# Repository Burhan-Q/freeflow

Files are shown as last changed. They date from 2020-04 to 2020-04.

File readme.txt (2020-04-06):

This project contains hardware design (schematics & layout) and firmware design for a
small PCB used to sense air flow and air pressure.  The intent is to use a 3D printed 
Venturi tube with this board to help with the current Covid-19 medical emergency.
The project has two potential uses:

- Part of a larger ventilator project.  The airflow sensor is a key component of a ventilator
  design.

- Stand alone use for sharing a commercial ventilator among multiple patients.
  One problem with sharing a ventilator between patients is equalizing the flow.
  This sensor can be used inline at each patient to allow the emergency workers 
  to regulate flow using flow valves.

Note that I locally maintain my projects using Mercurial (hg) and am pushing to github
using the hg-git plugin.  There may be some odd files in the repo (like .hgignore) due
to that.  These can be ignored.

The schematics and layout files here were made using the open source gEDA tools; gschem
for schematic capture and pcb for layout.  These tools can be downloaded here:
   http://www.geda-project.org/

As of 4/6/20 this project is in the early stages.  There have been two revisions of the PCB
(check the git history to see earlier versions).  The main difference is the type of sensors
used to measure the pressure drop across the venturi tube.

Firmware is working but very preliminary.  Things like calibration values are hard coded at
the moment.  It's under active development and changing rapidly.

I'll try to keep this file updated as things progress.

- Steve Glow

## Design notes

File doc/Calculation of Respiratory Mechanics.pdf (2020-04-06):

## Calculation of Respiratory Mechanics

# Introduction:

Respiratory mechanics refers to the expression of lung function through measures of pressure and flow. They are very useful to know the status of the lungs of ventilated patients. Below is the screen shot of Hamilton Medical ventilator monitoring menu. This document will try to calculate as much as possible parameters from this menu, using data input from our flow meter and pressure sensor. This should be noted that this is a developing document and will be updated periodically

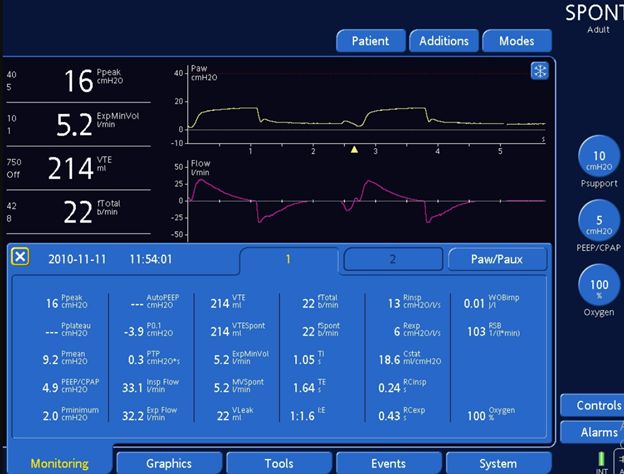
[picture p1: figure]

# 1) Alveolar Pressure:

For volume control setup like ours it’s calculated by

Palv = VT/CRS + PEEP.

VT <= set by us

PEEP<=set by us

CRS= calculated by Equation 6

# 2) Plateau Pressure

There are two methods to calculated it,

1) one is by holding the breath after inspiration for 0.5-1 second and measuring the pressure at inspiratory limb. This will be difficult in our setup of multiple patient.
2) The second method is using below equation and no hold breath maneuver is needed.

VT=tidal volume, set by us

PIP=peak inspiratory pressure , given by our pressure senor

PEEP=set by us

Time constant TE

is calculated by slope of expiratory flow curve between 0.1-0.5 seconds as shown below

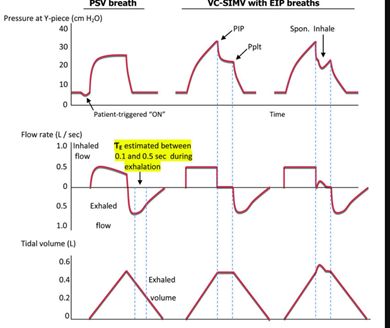
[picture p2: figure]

# 3) Auto-PEEP or iPEEP

Once again it can be calculated by two methods

a) Holding a breath after expiration and waiting for 0.5-1 second and measure pressing at proximal airway is Auto-PEEP, probably not applied in our case
b) It can also be calculated by mathematical equation

VT=tidal volume

CRS as calculated by equation-6

Kx=1/TE, and for TE see equation 2

# 4) Mean Airway Pressure

Calculated using following equation

PIP is peak inspiratory pressure

PEEP is known

TI

is time taken by respiration (SET BY US)

Ttot

total breathing cycle time

# 5) Respiratory System Compliance:

Defined in change in volume of respiratory system per unit of pressure

VT

=tidal volume

Pplat = See equation 2

PEEP=set by us

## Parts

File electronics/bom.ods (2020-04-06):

Item | Qty/board | Manufacturer | Part Number | Description | Value | Reference | Cost
1 | 1 | ST | STM32L412KBT6 | Processor |  | U1 | 2.46
2 | 1 | TI | TPS7B6933QDCYRQ1 | Linear regulator |  | U2 | 0.95
3 | 1 | JAE | DX4R005JJ2R1800 | Connector |  | J2 | 0.62
4 | 1 | Wurth | 150060VS75000 | LED | green | D3 | 0.11
5 | 1 | Wurth | 150060RS75000 | LED | red | D4 | 0.11
6 | 1 | CUI | CMT-0525-75-SMT-TR | Buzzer |  | U3 | 1.47
7 | 1 | Yageo | CC0603KRX7R9BB102 | Capacitor | 1nF | C3 | 0.01
8 | 1 | NXP | MP3V5004DP | Pressure sensor |  | U4
9 | 1 | NKK | A11JP | Switch |  | S2
10 | 2 | Yageo | RC0603FR-07150RL | Resistor | 150 | R1,R4 | 0.01
11 | 1 | Honeywell | MPRLS0001PG0000SA | Pressure sensor |  | U5 | 5.45
12 | 1 | E-switch | 800AWSP9M2QE | Push button |  | S3 | 2.41
13 | 4 | Toshiba | CUS10S30,H3F | Diode |  | D1,D5,D6,D7 | 0.1
14 | 1 | Nexperia | 74HC2G14GV,125 | Inverter |  | U7 | 0.21
15 | 1 | Yageo | CC0603KPX7R9BB103 | Capacitor | 0.01uF | C11 | 0.01
16 | 7 | Yageo | CC0603KRX7R8BB104 | Capacitor | 0.1uF | C12,C4,C5,C6,C7,C8,C9 | 0.01
17 | 1 | Samsung | CL10A105KP8NNNC | Capacitor | 1uF | C13 | 0.01
18 | 1 | Bourns | PEC12R-4222F-S0024 | Encoder |  | U8 | 0.8
19 | 1 | Hirose | DF13-2P-1.25DS(50) | Connector |  | J1 | 0.3
20 | 1 | Diodes Inc | DMN63D8LDW-7 | FET |  | Q1 | 0.1
21 | 1 | Hirose | DF13-4P-1.25DSA | Connector |  | J3 | 0.4
22 | 1 | Sullins | PPTC041LFBN-RC | Connector |  | J4 | 0.32
23 | 1 | Honeywell | HIH8120-021-001 | Humidity sensor |  | U6
24 | 1 | Molex | 705530003 | Connector |  | J5 | 0.8
25 | 8 | Yageo | RC0603FR-0710KL | Resistor | 10k | R10,R2,R3,R5,R6,R7,R8,R9 | 0.01
26 | 2 | Samsung | CL21A106KOQNNNG | Capacitor | 10uF | C1,C2 | 0.03

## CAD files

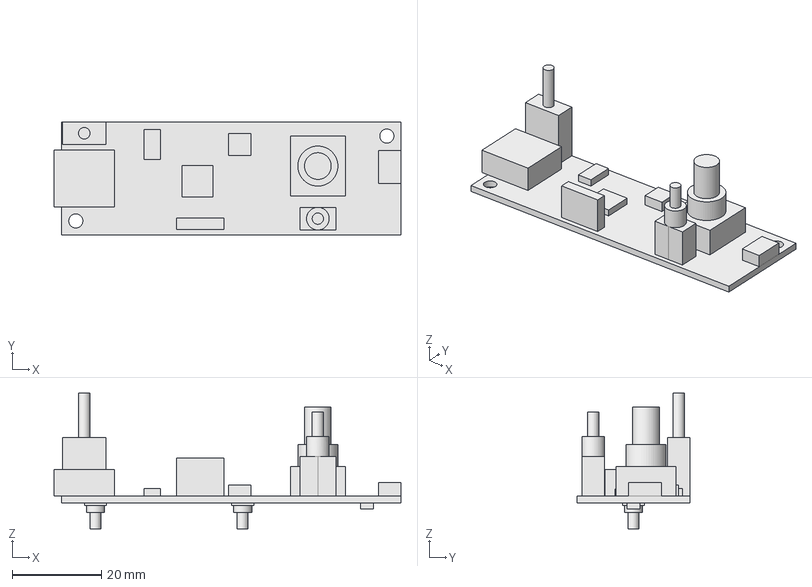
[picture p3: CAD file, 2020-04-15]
CAD/FreeFlow_board/freeflow2_ver2.step
77.9 x 25.4 x 30.5 mm

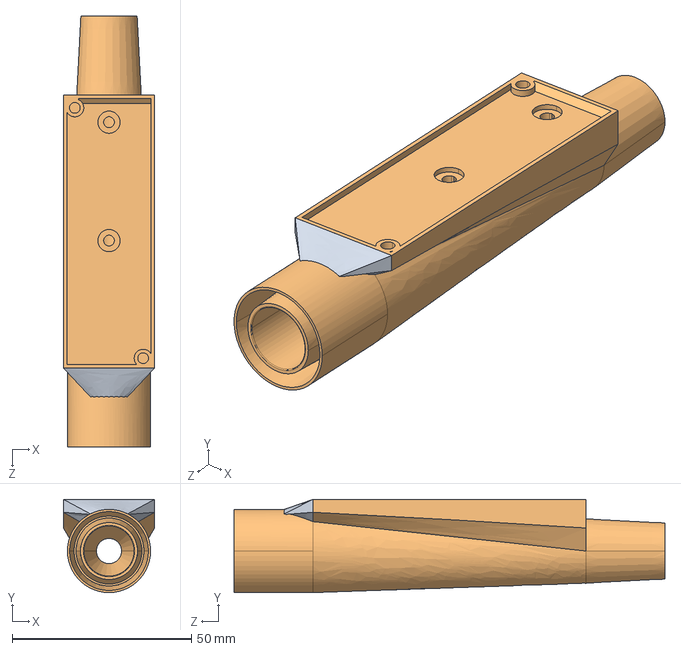
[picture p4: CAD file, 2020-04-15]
CAD/venturi/STEP/venturi_design_ver403.STEP
25.4 x 26.0 x 120.2 mm

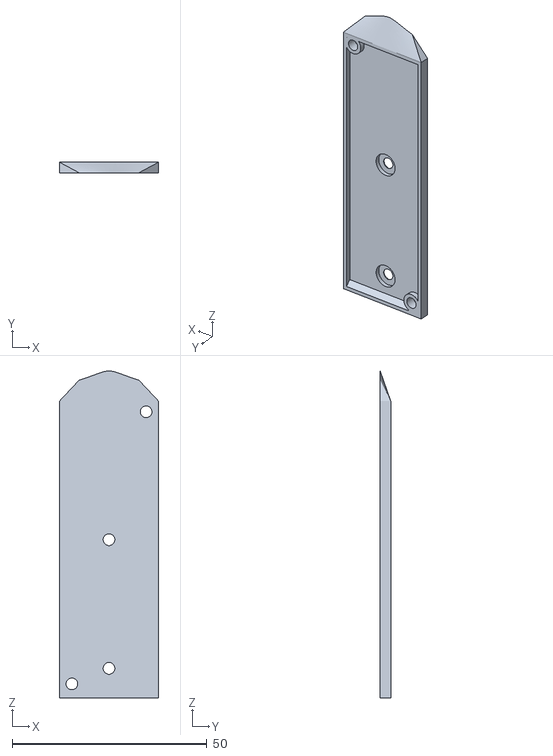
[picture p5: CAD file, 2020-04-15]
CAD/venturi/STL/venturi_design_ver403-board-mount.STL
25.4 x 2.70 x 83.9

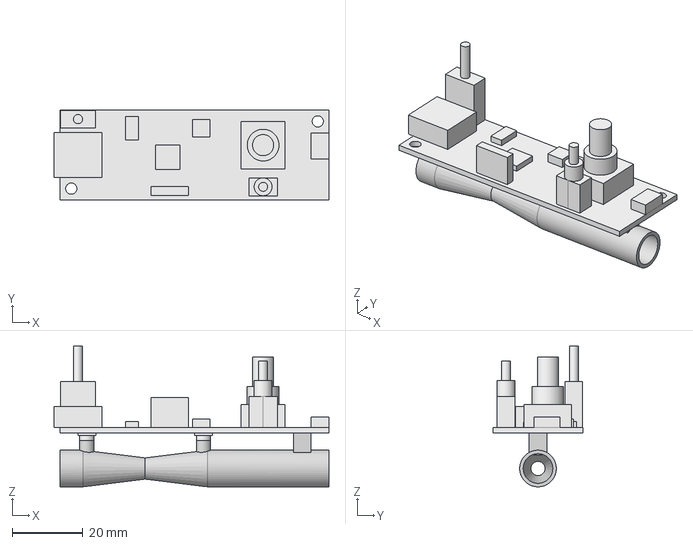
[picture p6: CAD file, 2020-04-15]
CAD/FreeFlow_board/freeflow2.stp
77.9 x 25.4 x 39.9 mm

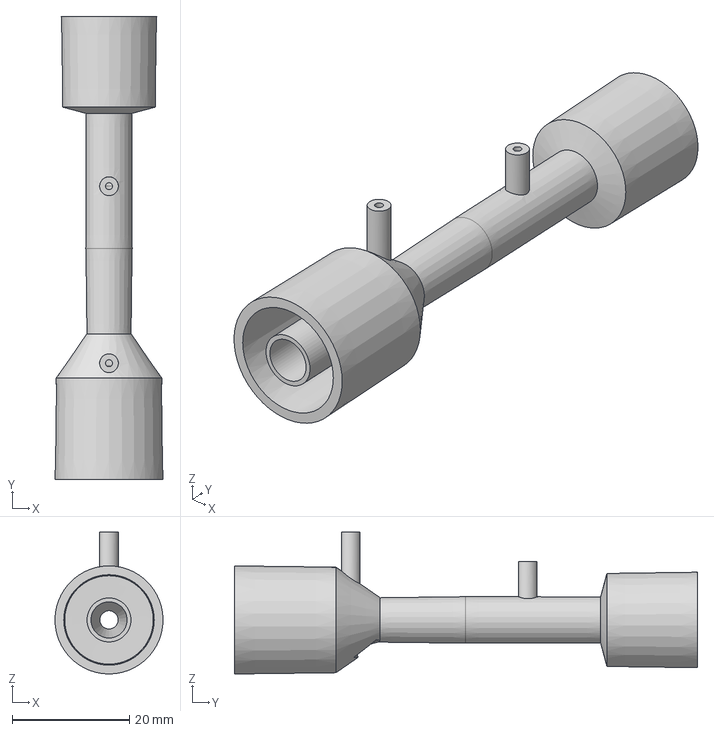
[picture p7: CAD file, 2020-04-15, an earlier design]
CAD/venturi/archive/TestV5.stp
18.5 x 79.1 x 24.2 mm

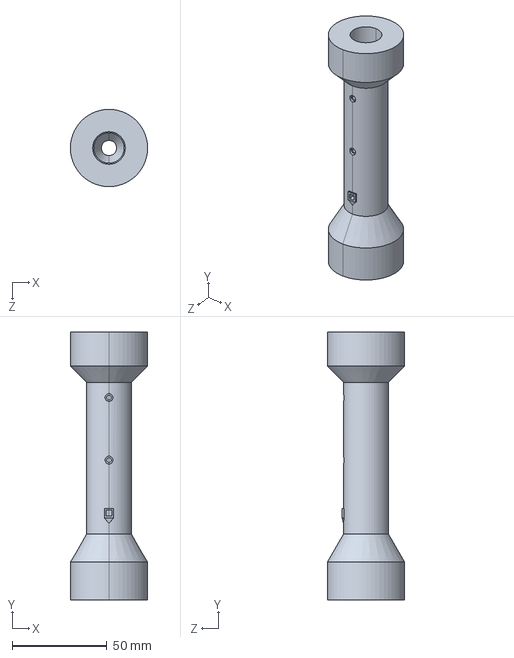
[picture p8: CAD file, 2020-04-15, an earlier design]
CAD/venturi/archive/venturi_design_ver104.STEP
40.8 x 141.4 x 40.8 mm

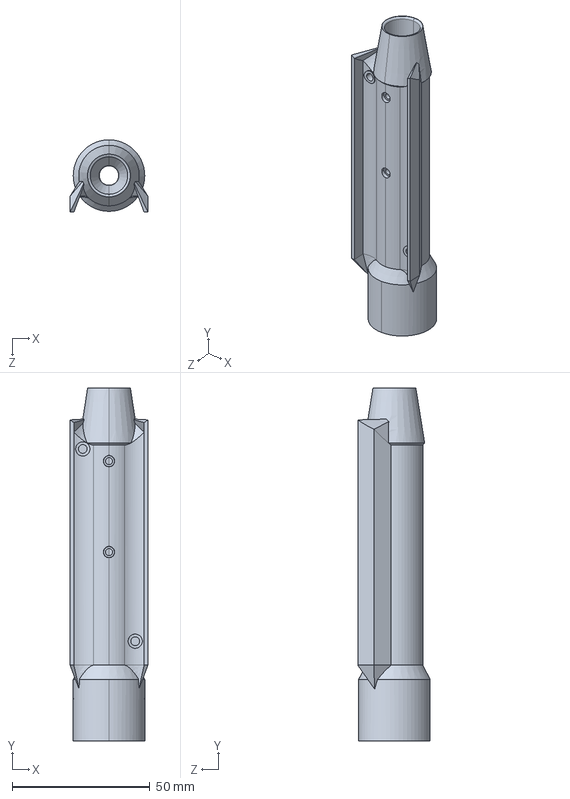
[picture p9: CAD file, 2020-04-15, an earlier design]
CAD/venturi/archive/venturi_design_ver207-3.STEP
28.3 x 128.2 x 26.3 mm

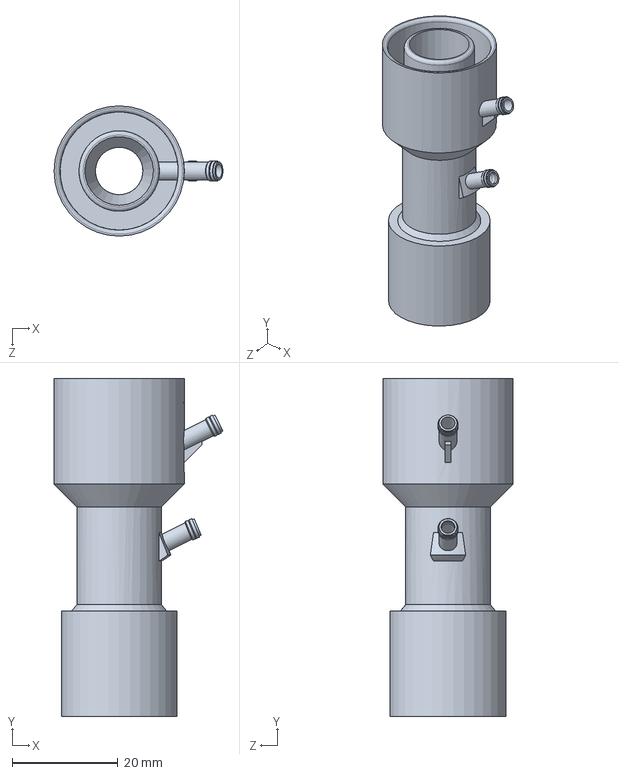
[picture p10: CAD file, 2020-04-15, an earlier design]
CAD/venturi/archive/venturi_design_ver002.SLDPRT
32.0 x 64.0 x 24.7 mm

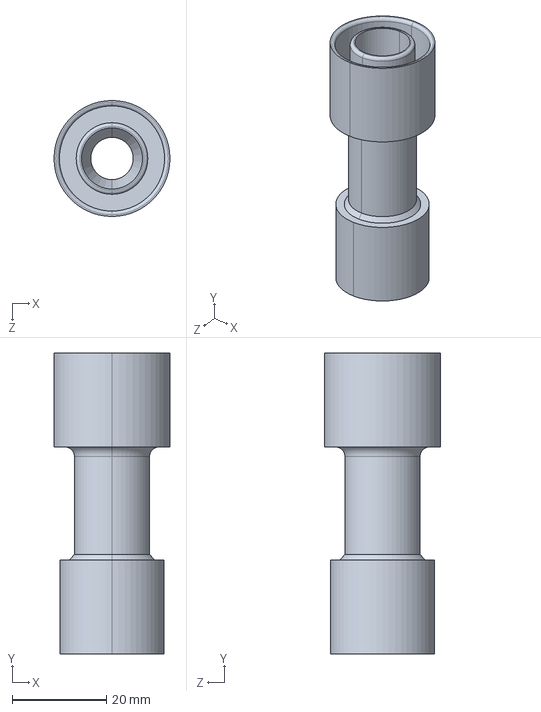
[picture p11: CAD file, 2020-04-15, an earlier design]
CAD/venturi/archive/venturi_design_ver001.STEP
24.7 x 64.0 x 24.7 mm

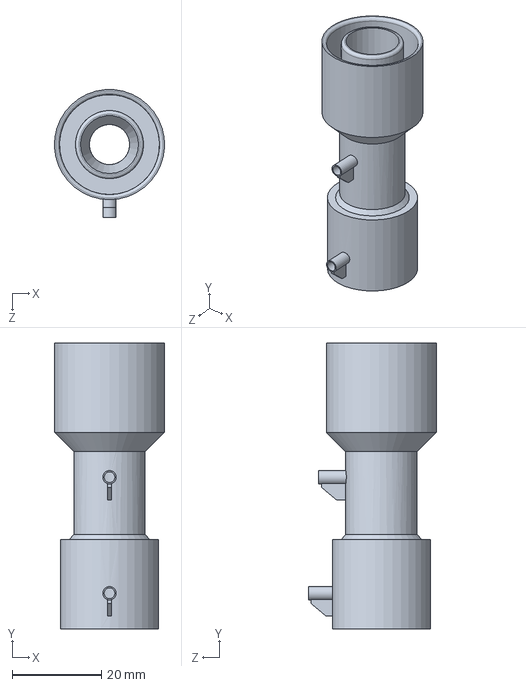
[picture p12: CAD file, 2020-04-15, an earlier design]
CAD/venturi/archive/venturi_design_ver003.SLDPRT
24.6 x 64.0 x 28.6 mm

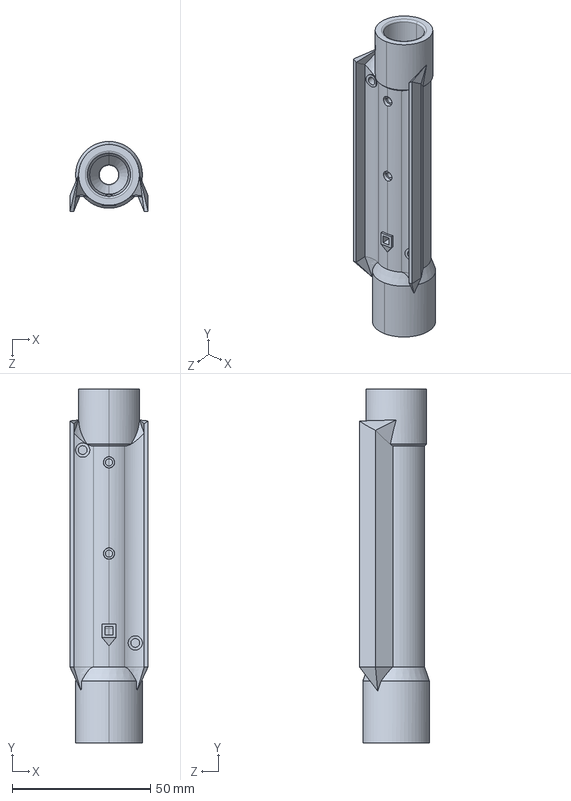
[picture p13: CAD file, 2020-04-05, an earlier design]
CAD/venturi/archive/venturi_design_ver207-1.STEP
28.3 x 128.2 x 25.4 mm

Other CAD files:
CAD/venturi/archive/venturi_design_ver004.STEP
CAD/venturi/archive/venturi_design_ver402.STEP
CAD/venturi/archive/venturi_design_ver207.STEP
CAD/FreeFlow_board/freeflow2.stl
CAD/venturi/STL/venturi_design_ver403.STL
CAD/venturi/archive/TestV5.stl
CAD/venturi/archive/venturi_design_ver001.SLDPRT
CAD/venturi/archive/venturi_design_ver004.SLDPRT
CAD/venturi/archive/venturi_design_ver104.STL
CAD/venturi/archive/venturi_design_ver207-1.STL
CAD/venturi/archive/venturi_design_ver207-3.STL
CAD/venturi/archive/venturi_design_ver207.STL
CAD/venturi/archive/venturi_design_ver402.STL

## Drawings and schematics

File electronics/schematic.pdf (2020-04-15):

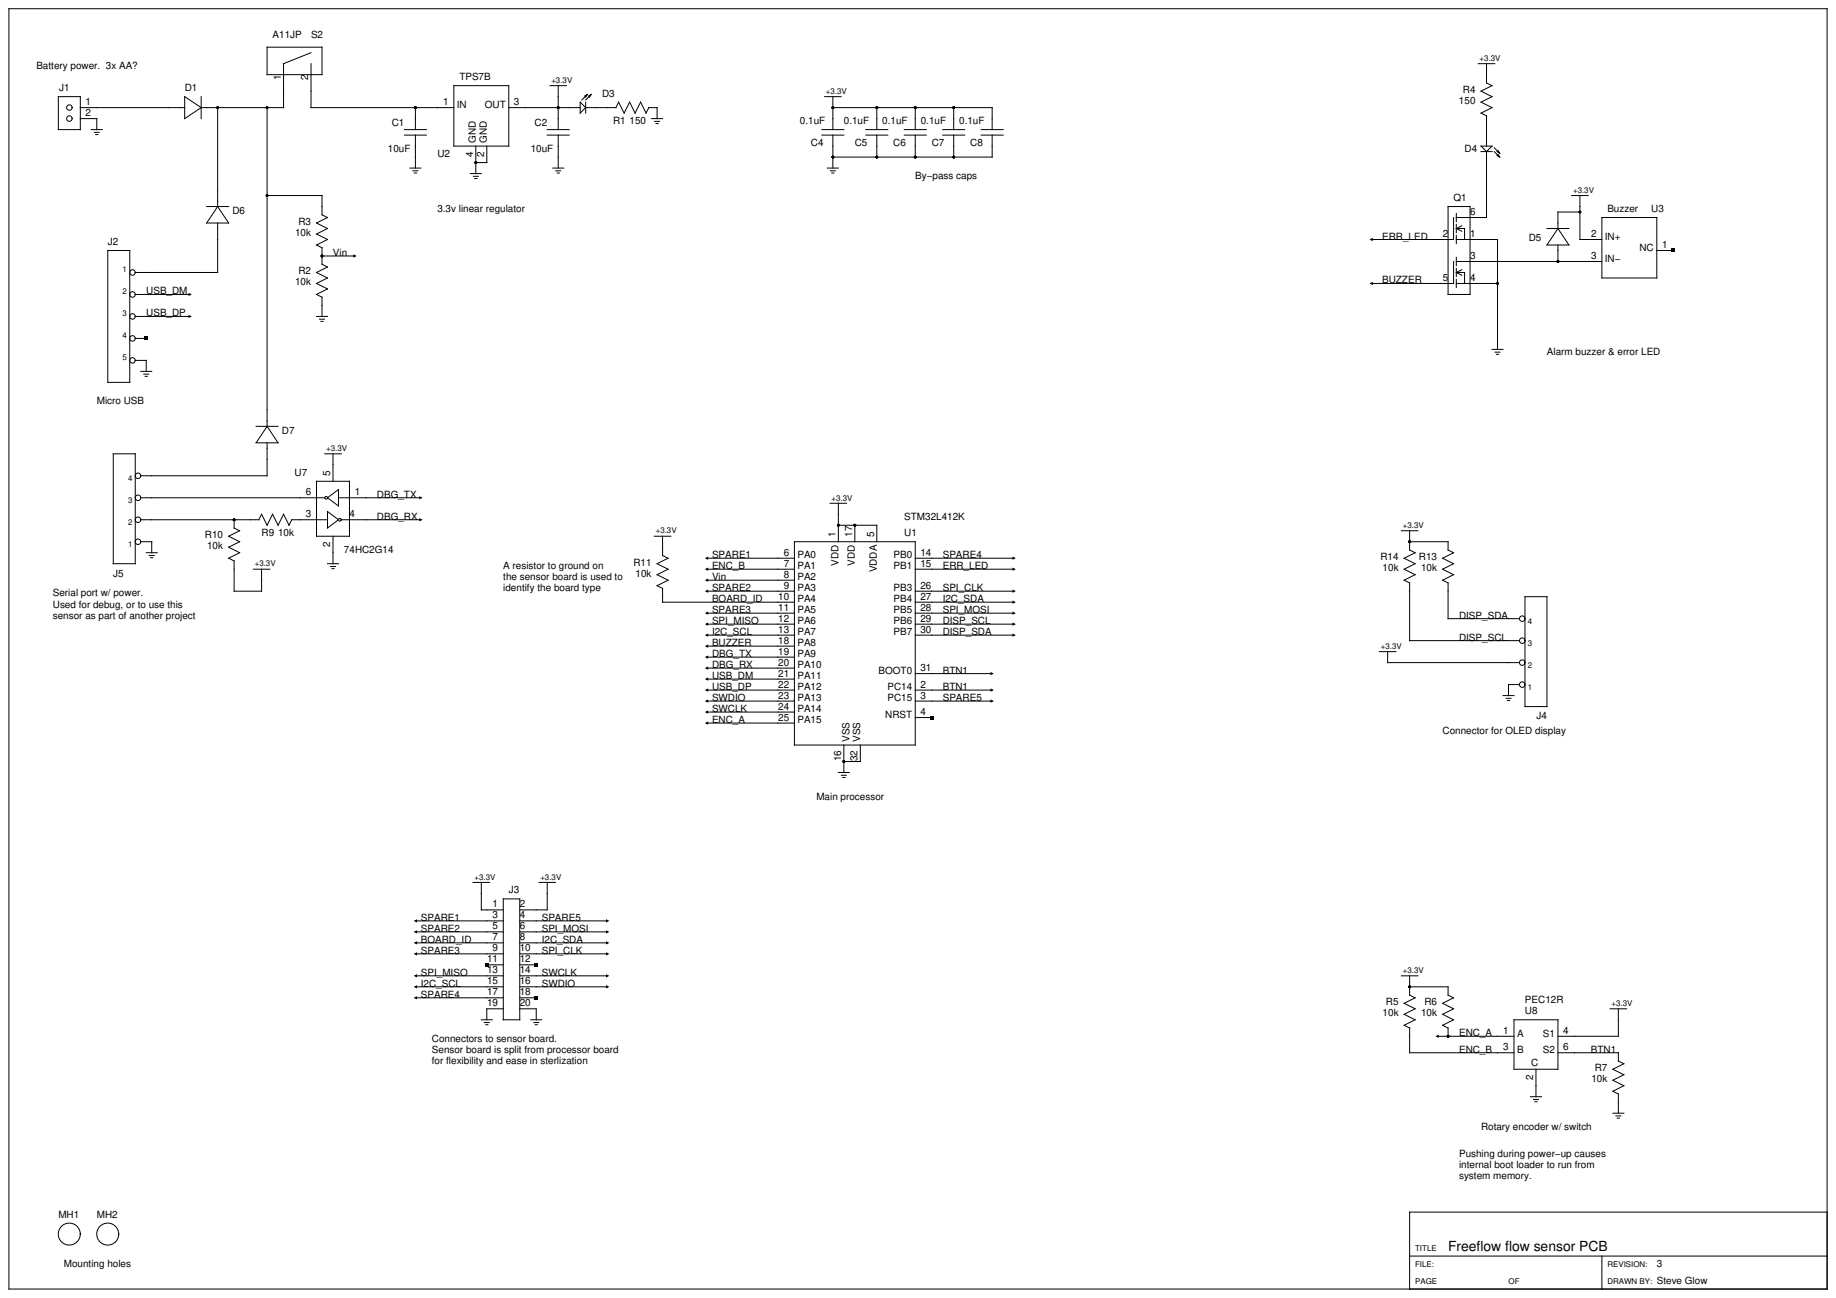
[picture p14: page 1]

Alarm buzzer & error LED

A resistor to ground on
the sensor board is used to
identify the board type

Serial port w/ power.
Used for debug, or to use this
sensor as part of another project

Connector for OLED display

Connectors to sensor board.
Sensor board is split from processor board
for flexibility and ease in sterlization

Pushing during power−up causes
internal boot loader to run from
system memory.

Freeflow flow sensor PCB

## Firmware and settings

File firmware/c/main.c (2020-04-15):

/* main.c */

#include "adc.h"
#include "buzzer.h"
#include "cpu.h"
#include "display.h"
#include "encoder.h"
#include "io.h"
#include "loop.h"
#include "pressure.h"
#include "sercmd.h"
#include "store.h"
#include "timer.h"
#include "trace.h"
#include "uart.h"
#include "ui.h"
#include "utils.h"

int main( void )
{
   // I use the first 128 bytes of RAM as a scratch
   // pad area for debugging.  Clear that data out
   // initially.
   for( int i=0; i<32; i++ )
      dbgLong[i] = 0;

   // Init the processor and various modules
   CPU_Init();
   StoreInit();
GPIO_Output( DIGIO_A_BASE, 7, 0 );
   UART_Init();
   BuzzerInit();
   InitEncoder();
   IntiIO();
   TimerInit();
   LoopInit();
   AdcInit();
   TraceInit();
   InitPressure();
   InitDisplay();
   InitUserInteface();

   LoopStart();

   // The main loop handles lower priority background tasks
   // The higher priority work is done in interrupt handlers.
   while( 1 )
   {
      PollSerCmd();
      BuzzerPoll();
      PollIO();
      PollUserInteface();
      BkgPollPressure();
   }
}

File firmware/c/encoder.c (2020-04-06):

/* encoder.c */

#include "cpu.h"
#include "encoder.h"

// The board includes a rotary encoder which can be used
// to enter settings.
//
// The two encoder lines are on PA15 and PA1.
// Those two inputs can be tied to timer 2 channels 1 and 2.

void InitEncoder( void )
{
   // Configure the two pins for use by timer 2
   GPIO_PinAltFunc( DIGIO_A_BASE,  1, 1 );
   GPIO_PinAltFunc( DIGIO_A_BASE, 15, 1 );

   TimerRegs *tmr = (TimerRegs *)TIMER2_BASE;

   // Select encoder input mode for the timer
   tmr->slaveCtrl = 0x00000003;

   // Add filters to the clock inputs.
   tmr->ccMode[0] = 0x0000F1F1;

   // Set the reload register to the max value.
   // Pity to use the only 32-bit counter for this, but
   // it's just how the I/O worked out.
   tmr->reload    = 0xFFFFFFFF;

   // Enable the timer
   tmr->ctrl[0]   = 0x00000001;
}

// Get the current encoder count value
int GetEncoderCount( void )
{
   TimerRegs *tmr = (TimerRegs *)TIMER2_BASE;
   return tmr->counter;
}

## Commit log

2020-04-05 Upload of latest venturi valve design
    ver207 :: pressure port diameter = 3mm
    ver207-1 :: pressure port diameter = 2.57mm
    [venturi_design_ver207-1.STEP, venturi_design_ver207-1.STL, venturi_design_ver207.STEP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]
2020-04-15 Current design
    [venturi_design_ver403-board-mount.STL, venturi_design_ver403.STEP]
